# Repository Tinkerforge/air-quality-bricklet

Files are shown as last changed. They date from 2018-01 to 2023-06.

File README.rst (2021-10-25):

Air Quality Bricklet
====================

This repository contains the firmware source code and the hardware design
files. The documentation generator configs can be found at
https://github.com/Tinkerforge/generators

Repository Content
------------------

software/:
 * examples/: Examples for all supported languages
 * build/: Compiled files
 * src/: Source code of firmware
 * Makefile: Makefile to build project

hardware/:
 * Contains KiCad project files and additionally schematics as PDF

datasheets/:
 * Contains datasheets for sensors and complex ICs that are used

Hardware
--------

The hardware is designed with the open source EDA Suite KiCad
(http://www.kicad.org). Before you are able to open the files,
you have to install the Tinkerforge kicad-libraries
(https://github.com/Tinkerforge/kicad-libraries). You can either clone
them directly in hardware/ or clone them in a separate folder and
symlink them into hardware/
(ln -s kicad_path/kicad-libraries project_path/hardware). After that you
can open the .pro file in hardware/ with KiCad and from there view and
modify the schematics and the PCB layout.

Software
--------

If you want to do your own Brick/Bricklet firmware development we highly
recommend that you use our build environment setup script and read the
tutorial (https://www.tinkerforge.com/en/doc/Tutorials/Tutorial_Build_Environment/Tutorial.html).

To compile the C code we recommend you to install the newest GNU Arm Embedded
Toolchain (https://launchpad.net/gcc-arm-embedded/+download).
You also need to install bricklib2 (https://github.com/Tinkerforge/bricklib2).

You can either clone it directly in software/src/ or clone it in a
separate folder and symlink it into software/src/
(ln -s bricklib_path/bricklib2 project_path/software/src/). Finally make sure to
have CMake installed (http://www.cmake.org/cmake/resources/software.html).

After that you can build the firmware by invoking make in software/.
The firmware (.zbin) can then be found in software/build/ and uploaded
with brickv (click button "Flashing" on start screen).

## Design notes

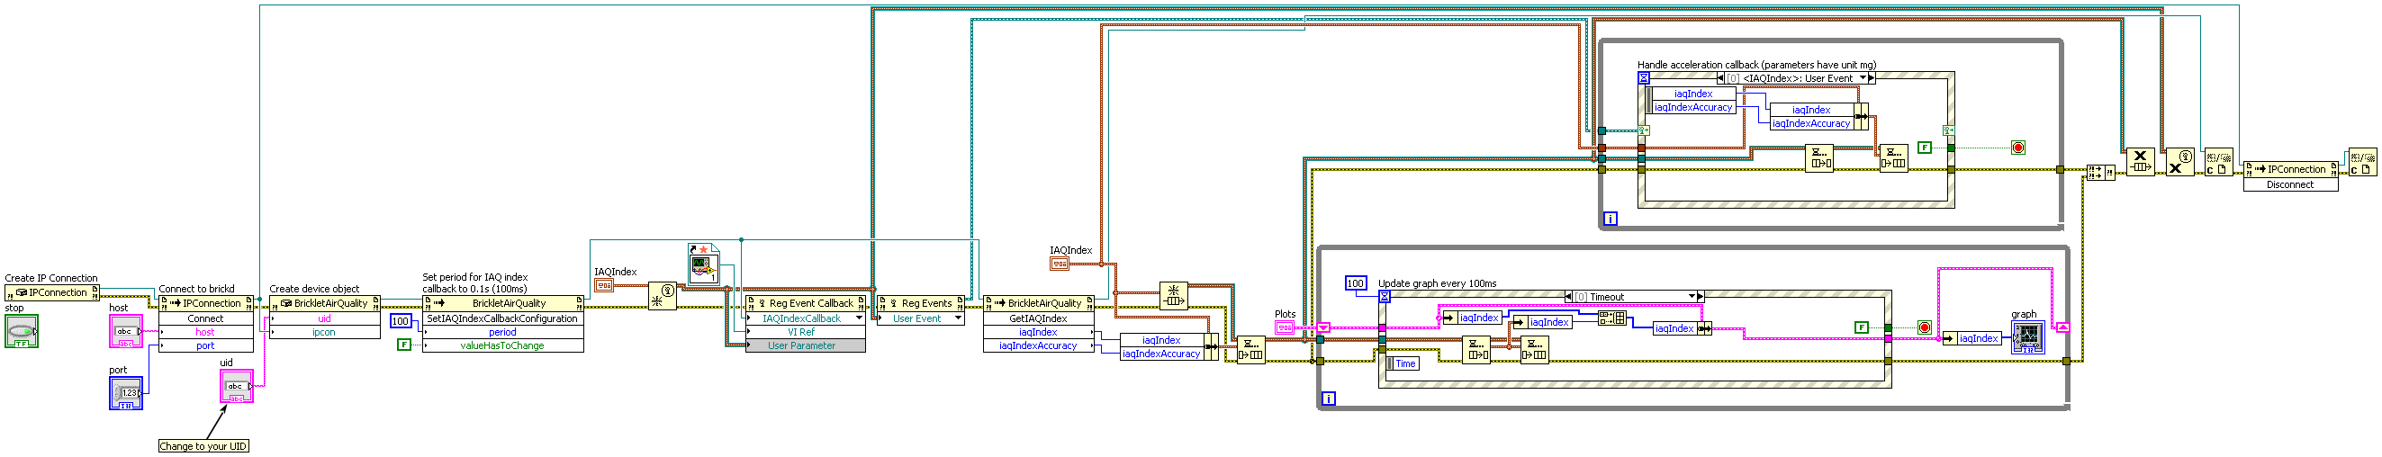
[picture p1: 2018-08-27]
software/examples/labview/Example Graph.vi.png

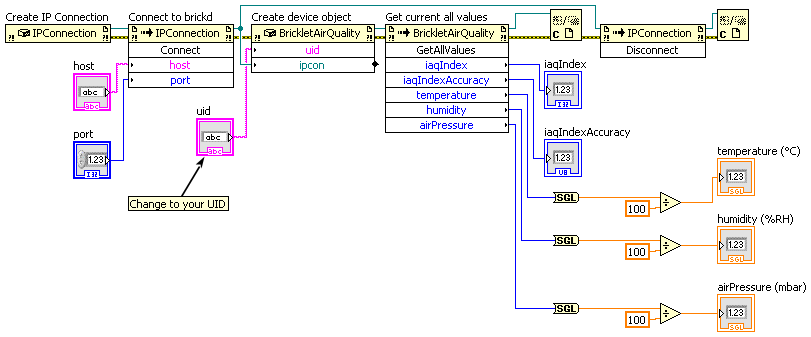
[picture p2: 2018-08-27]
software/examples/labview/Example Simple.vi.png

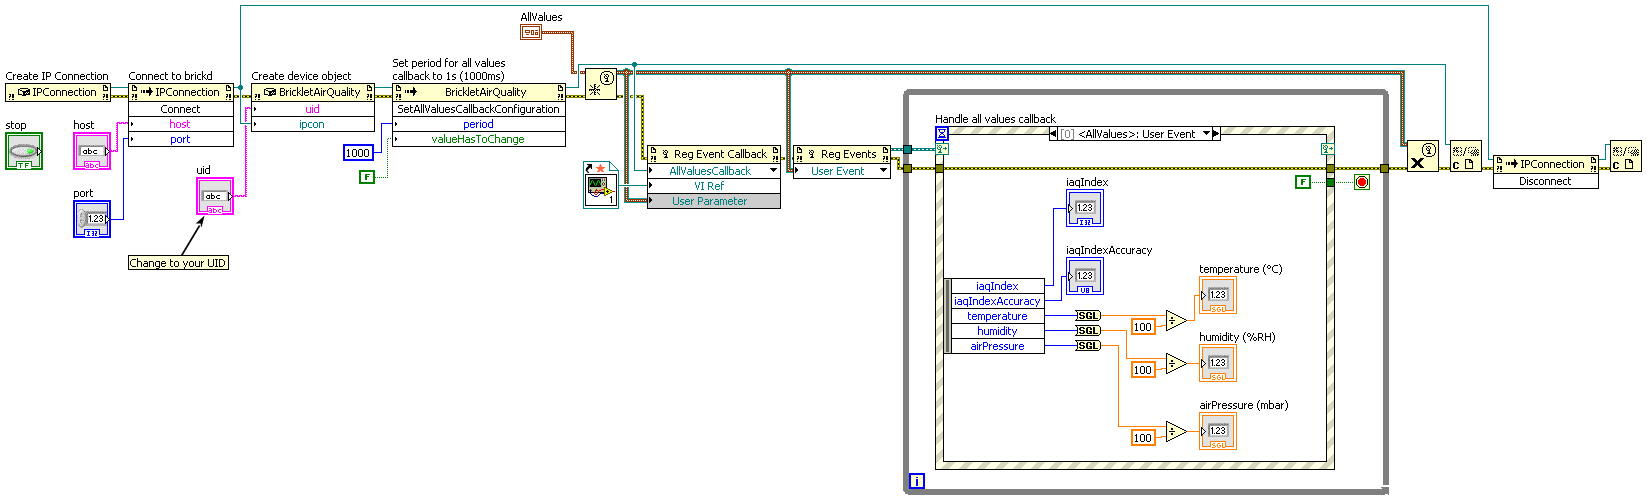
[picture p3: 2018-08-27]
software/examples/labview/Example Callback.vi.png

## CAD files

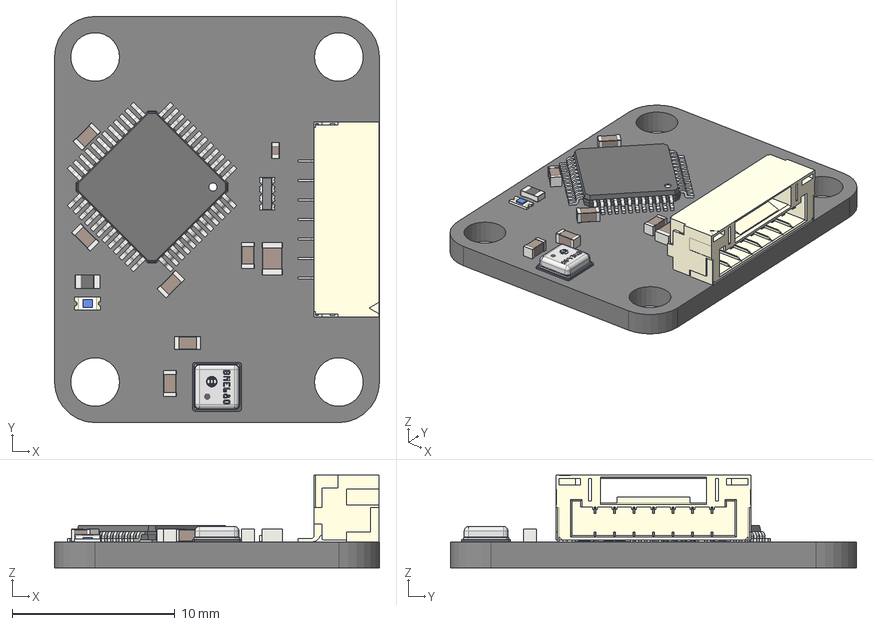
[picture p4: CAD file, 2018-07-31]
hardware/air-quality.step
20.0 x 25.0 x 5.70 mm
Pcb
lqfp48_7x7_p05_
BME680_
C_0603_
C_0603_001
C_0603_002
C_0805_
C_0402_
C_0603_003
C_0603_004
C_0603_005
D_0603_blue_
BrickletConn_7pin_
R_0603_

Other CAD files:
hardware/air-quality.FCStd

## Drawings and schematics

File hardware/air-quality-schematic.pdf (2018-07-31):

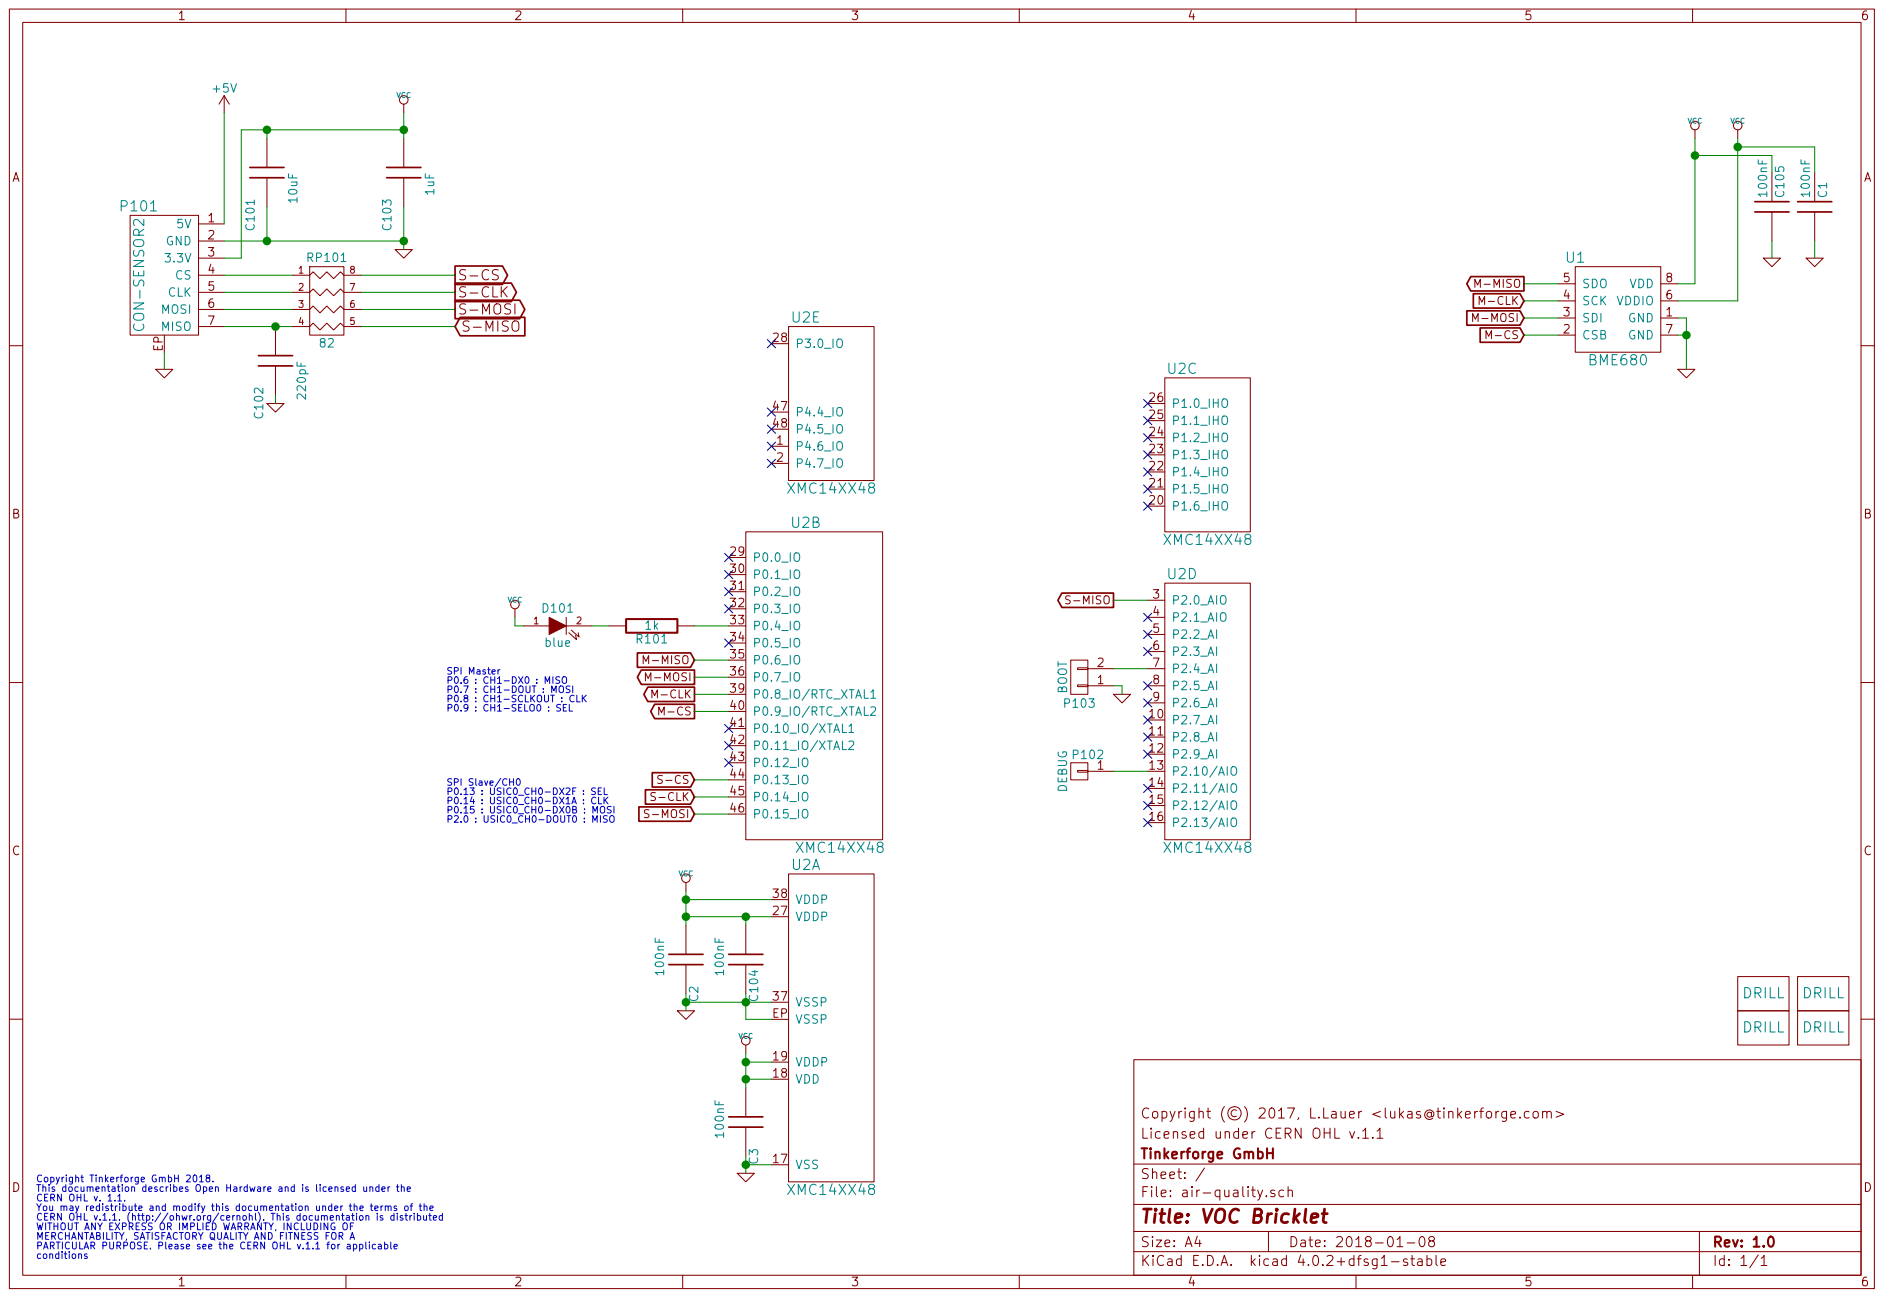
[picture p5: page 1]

VCC SPI Slave/CH0 P0.13 : USIC0_CH0-DX2F : SEL P0.14 : USIC0_CH0-DX1A : CLK

SPI Master P0.6 : CH1-DX0 : MISO
P0.7 : CH1-DOUT : MOSI P0.8 : CH1-SCLKOUT : CLK

Licensed under CERN OHL v.1.1 Copyright (©) 2017, L.Lauer <lukas@tinkerforge.com>

File: air-quality.sch Sheet: / Tinkerforge GmbH

Copyright Tinkerforge GmbH 2018. This documentation describes Open Hardware and is licensed under the CERN OHL v. 1.1. You may redistribute and modify this documentation under the terms of the CERN OHL v.1.1. (http://ohwr.org/cernohl). This documentation is distributed WITHOUT ANY EXPRESS OR IMPLIED WARRANTY, INCLUDING OF MERCHANTABILITY, SATISFACTORY QUALITY AND FITNESS FOR A

Id: 1/1 Title: VOC Bricklet

PARTICULAR PURPOSE. Please see the CERN OHL v.1.1 for applicable

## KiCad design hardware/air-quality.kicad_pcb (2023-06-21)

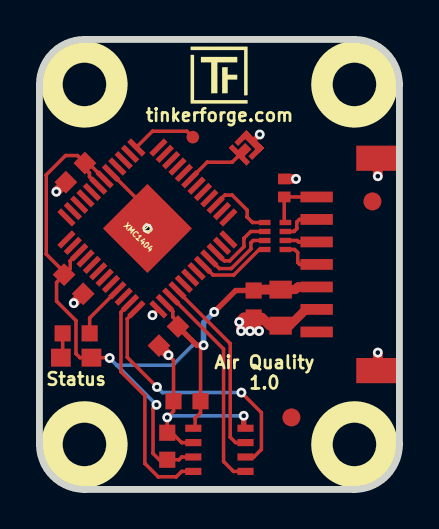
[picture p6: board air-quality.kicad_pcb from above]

Board: 2 copper layers, 20.0 x 25.0 mm, 23 parts (1 on the bottom side), 18 nets.

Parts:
C1, C2, C3, C104, C105: 100nF; C0603F
C101: 10uF; C0805
C102: 220pF; C0402F
C103: 1uF; C0603F
D101: blue; D0603E
Fiducial_Mark: VAL**; Fiducial_Mark
Fiducial_Mark#2: VAL**; Fiducial_Mark
P101: CON-SENSOR2
P102: DEBUG; DEBUG_PAD
P103: BOOT; SolderJumper
R101: 1k; R0603F
RP101: 82; 4X0402
U1: BME680
U2: XMC1404; QFN48-EP2
U103, U104, U105, U106: DRILL; DRILL_NP
VAL: CE_5mm

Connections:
GND: C1.2, C2.2, C3.2, C101.1, C102.1, C103.1, C104.2, C105.2, P101.2, P101.EP, P103.1, U1.1, U1.7, U2.17, U2.37, U2.EP
M-CLK: U1.4, U2.39
M-CS: U1.2, U2.40
M-MISO: U1.5, U2.35
M-MOSI: U1.3, U2.36
unnamed: C102.2, P101.7, RP101.4
unnamed: D101.2, R101.2
unnamed: P101.4, RP101.1
unnamed: P101.5, RP101.2
unnamed: P101.6, RP101.3
unnamed: P102.1, U2.13
unnamed: P103.2, U2.7
unnamed: R101.1, U2.33
S-CLK: RP101.7, U2.45
S-CS: RP101.8, U2.44
S-MISO: RP101.5, U2.3
S-MOSI: RP101.6, U2.46
VCC: C1.1, C2.1, C3.1, C101.2, C103.2, C104.1, C105.1, D101.1, P101.3, U1.6, U1.8, U2.18, U2.19, U2.27, U2.38

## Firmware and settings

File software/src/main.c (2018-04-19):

/* air-quality-bricklet
 * Copyright (C) 2017 Olaf Lüke <olaf@tinkerforge.com>
 *
 * main.c: Initialization for Air Quality Bricklet
 *
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
 * You should have received a copy of the GNU Lesser General Public
 * License along with this library; if not, write to the
 * Free Software Foundation, Inc., 59 Temple Place - Suite 330,
 * Boston, MA 02111-1307, USA.
 */

#include <stdio.h>
#include <stdbool.h>

#include "configs/config.h"

#include "bricklib2/bootloader/bootloader.h"
#include "bricklib2/hal/system_timer/system_timer.h"
#include "bricklib2/logging/logging.h"
#include "communication.h"
#include "voc.h"

int main(void) {
	logging_init();
	logd("Start Air Quality Bricklet\n\r");

	communication_init();
	voc_init();

	while(true) {
		bootloader_tick();
		communication_tick();
		voc_tick();
	}
}

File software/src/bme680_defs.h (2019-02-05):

/**
 * Copyright (C) 2017 - 2018 Bosch Sensortec GmbH
 *
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
 * Redistributions of source code must retain the above copyright
 * notice, this list of conditions and the following disclaimer.
 *
 * Redistributions in binary form must reproduce the above copyright
 * notice, this list of conditions and the following disclaimer in the
 * documentation and/or other materials provided with the distribution.
 *
 * Neither the name of the copyright holder nor the names of the
 * contributors may be used to endorse or promote products derived from
 * this software without specific prior written permission.
 *
 * THIS SOFTWARE IS PROVIDED BY THE COPYRIGHT HOLDERS AND
 * CONTRIBUTORS "AS IS" AND ANY EXPRESS OR
 * IMPLIED WARRANTIES, INCLUDING, BUT NOT LIMITED TO, THE IMPLIED
 * WARRANTIES OF MERCHANTABILITY AND FITNESS FOR A PARTICULAR PURPOSE ARE
 * DISCLAIMED. IN NO EVENT SHALL COPYRIGHT HOLDER
 * OR CONTRIBUTORS BE LIABLE FOR ANY
 * DIRECT, INDIRECT, INCIDENTAL, SPECIAL, EXEMPLARY,
 * OR CONSEQUENTIAL DAMAGES(INCLUDING, BUT NOT LIMITED TO,
 * PROCUREMENT OF SUBSTITUTE GOODS OR SERVICES;
 * LOSS OF USE, DATA, OR PROFITS; OR BUSINESS INTERRUPTION)
 * HOWEVER CAUSED AND ON ANY THEORY OF LIABILITY,
 * WHETHER IN CONTRACT, STRICT LIABILITY, OR TORT
 * (INCLUDING NEGLIGENCE OR OTHERWISE) ARISING IN
 * ANY WAY OUT OF THE USE OF THIS
 * SOFTWARE, EVEN IF ADVISED OF THE POSSIBILITY OF SUCH DAMAGE
 *
 * The information provided is believed to be accurate and reliable.
 * The copyright holder assumes no responsibility
 * for the consequences of use
 * of such information nor for any infringement of patents or
 * other rights of third parties which may result from its use.
 * No license is granted by implication or otherwise under any patent or
 * patent rights of the copyright holder.
 *
 * @file	bme680_defs.h
 * @date	19 Jun 2018
 * @version	3.5.9
 * @brief
 *
 */

/*! @file bme680_defs.h
 @brief Sensor driver for BME680 sensor */
/*!
 * @defgroup BME680 SENSOR API
 * @brief
 * @{*/
#ifndef BME680_DEFS_H_
#define BME680_DEFS_H_

/********************************************************/
/* header includes */
#ifdef __KERNEL__
#include <linux/types.h>
#include <linux/kernel.h>
#else
#include <stdint.h>
#include <stddef.h>
#endif

/******************************************************************************/
/*! @name		Common macros					      */
/******************************************************************************/

#if !defined(UINT8_C) && !defined(INT8_C)
#define INT8_C(x)       S8_C(x)
#define UINT8_C(x)      U8_C(x)
#endif

#if !defined(UINT16_C) && !defined(INT16_C)
#define INT16_C(x)      S16_C(x)
#define UINT16_C(x)     U16_C(x)
#endif

#if !defined(INT32_C) && !defined(UINT32_C)
#define INT32_C(x)      S32_C(x)
#define UINT32_C(x)     U32_C(x)
#endif

#if !defined(INT64_C) && !defined(UINT64_C)
#define INT64_C(x)      S64_C(x)
#define UINT64_C(x)     U64_C(x)
#endif

/**@}*/

/**\name C standard macros */
#ifndef NULL
#ifdef __cplusplus
#define NULL   0
#else
#define NULL   ((void *) 0)
#endif
#endif

/** BME680 configuration macros */
/** Enable or un-comment the macro to provide floating point data output */
#ifndef BME680_FLOAT_POINT_COMPENSATION
	#define BME680_FLOAT_POINT_COMPENSATION 
#endif

/** BME680 General config */
#define BME680_POLL_PERIOD_MS		UINT8_C(10)

/** BME680 I2C addresses */
#define BME680_I2C_ADDR_PRIMARY		UINT8_C(0x76)
#define BME680_I2C_ADDR_SECONDARY	UINT8_C(0x77)

/** BME680 unique chip identifier */
#define BME680_CHIP_ID  UINT8_C(0x61)

/** BME680 coefficients related defines */
#define BME680_COEFF_SIZE		UINT8_C(41)
#define BME680_COEFF_ADDR1_LEN		UINT8_C(25)
#define BME680_COEFF_ADDR2_LEN		UINT8_C(16)

/** BME680 field_x related defines */
#define BME680_FIELD_LENGTH		UINT8_C(15)
#define BME680_FIELD_ADDR_OFFSET	UINT8_C(17)

/** Soft reset command */
#define BME680_SOFT_RESET_CMD   UINT8_C(0xb6)

/** Error code definitions */
#define BME680_OK		INT8_C(0)
/* Errors */
#define BME680_E_NULL_PTR		    INT8_C(-1)
#define BME680_E_COM_FAIL		    INT8_C(-2)
#define BME680_E_DEV_NOT_FOUND		INT8_C(-3)
#define BME680_E_INVALID_LENGTH		INT8_C(-4)

/* Warnings */
#define BME680_W_DEFINE_PWR_MODE	INT8_C(1)
#define BME680_W_NO_NEW_DATA        INT8_C(2)

/* Info's */
#define BME680_I_MIN_CORRECTION		UINT8_C(1)
#define BME680_I_MAX_CORRECTION		UINT8_C(2)

/** Register map */
/** Other coefficient's address */
#define BME680_ADDR_RES_HEAT_VAL_ADDR	UINT8_C(0x00)
#define BME680_ADDR_RES_HEAT_RANGE_ADDR	UINT8_C(0x02)
#define BME680_ADDR_RANGE_SW_ERR_ADDR	UINT8_C(0x04)
#define BME680_ADDR_SENS_CONF_START	UINT8_C(0x5A)
#define BME680_ADDR_GAS_CONF_START	UINT8_C(0x64)

/** Field settings */
#define BME680_FIELD0_ADDR		UINT8_C(0x1d)

/** Heater settings */
#define BME680_RES_HEAT0_ADDR		UINT8_C(0x5a)
#define BME680_GAS_WAIT0_ADDR		UINT8_C(0x64)
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

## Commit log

2017-11-13 Add initial schematic
    [voc.sch]
2017-11-13 Add initial PCB
    [voc.kicad_pcb]
2017-11-14 Add routing for BME680
    [voc.kicad_pcb]
2018-01-04 Change CoMCU to XMC1400
    [voc.sch]
2018-01-04 Change Boot, Debug und Status LED pins
    [voc.sch]
2018-01-04 Change XMC1100 to XMC1400 footprint
    [voc.kicad_pcb]
2018-01-08 Fix version
    [voc.kicad_pcb]
2018-01-08 Change some new years things
    [voc.sch]
2018-02-20 Cleanup KiCad libraries config
    Ensure LibDir=kicad-libraries and LibName1=tinkerforge.
    Remove special library.
2018-03-20 Add firmware
    [cmake_config_custom.txt]
2018-03-22 Fix bugs in save state/load
    [voc.c]
2018-03-22 use 3.9°C offset (calibrated with VA720 calibrator)
2018-04-19 rename voc bricklet to air quality bricklet
    [air_quality.kicad_pcb, air_quality.sch]
2018-06-06 fix status text, set origin
    [air_quality.kicad_pcb]
2018-06-07 fix wrong bypass capacitor connection, remove copper plane from sensor, increase sensor footprint pad size
    [air_quality.kicad_pcb, air_quality.sch]
2018-06-11 Rename files
    [air-quality.kicad_pcb, air-quality.sch]
2018-06-18 Change capacitor footprint(s) to C0402F
    [air-quality.kicad_pcb, air-quality.sch]
2018-07-11 Fix origin
    [air-quality.kicad_pcb]
2018-07-17 specify processor
    [air-quality.kicad_pcb, air-quality.sch]
2018-07-31 Add 3d model (*.FCStd & .step)
    [air-quality.FCStd, air-quality.step]
2018-07-31 Add PDF schematic
2018-09-10 examples: Fix callback configuration
    [example_callback.c]
2018-10-12 Change rate from 1 SPS to 0.3SPS
    This results in a decrease of self-heating from 3.9 to 0.5°C!
2018-12-14 go: Fix printf parameters.
2019-01-04 Fix temperature offset (use 1/100 °C instead of °C)
    [voc.c]
2019-02-08 Add API for changing background calibration duration
2019-02-22 fixed libary, added sym-lib-table, changed processor to XMC1404
    [air-quality.kicad_pcb, air-quality.sch]
2019-03-07 Disable automatic calibration load/save for now
    This is broken in BSEC v1.4.7.1 and it is not clear when a fixed version will be released
    [config_bme680.h, voc.c]
2019-08-22 c: Adapt to bindings changes
    [example_callback.c]
2020-08-31 uc: Use fixed-with placeholders in format strings.
    [example_callback.c, example_simple.c]
2020-09-02 uc: Add example driver note.
2020-10-16 uc: Fix divisor type.
    [example_callback.c]
2021-07-12 Update BSEC to 1.4.8.0
    - reactivate auto-calibration
    - use 1 page for calibration save/load instead of 2
    - increase work buffer and coop task stack size
2021-10-25 Update KiCad link
    https://www.kicad.org/blog/2021/10/Avoid-links-to-former-kicad-domain/
2022-04-27 uc: Adapt to bindings changes
    [example_callback.c, example_simple.c]
2023-06-21 update to new kicad version
    [air-quality.kicad_pcb, air-quality.kicad_sch, air-quality.sch]

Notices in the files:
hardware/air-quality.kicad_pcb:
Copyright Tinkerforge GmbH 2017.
